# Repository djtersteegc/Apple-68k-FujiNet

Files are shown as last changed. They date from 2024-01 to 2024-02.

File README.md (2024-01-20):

Repo for early testing of FujiNet PCB's for 68k Apple Macs

# Rev0

Schematic - https://djtersteegc.github.io/Apple-68k-FujiNet/Apple-68k-FujiNet-Rev0-Schematic.pdf

Interactive BOM - https://djtersteegc.github.io/Apple-68k-FujiNet/ibom-Rev0.html

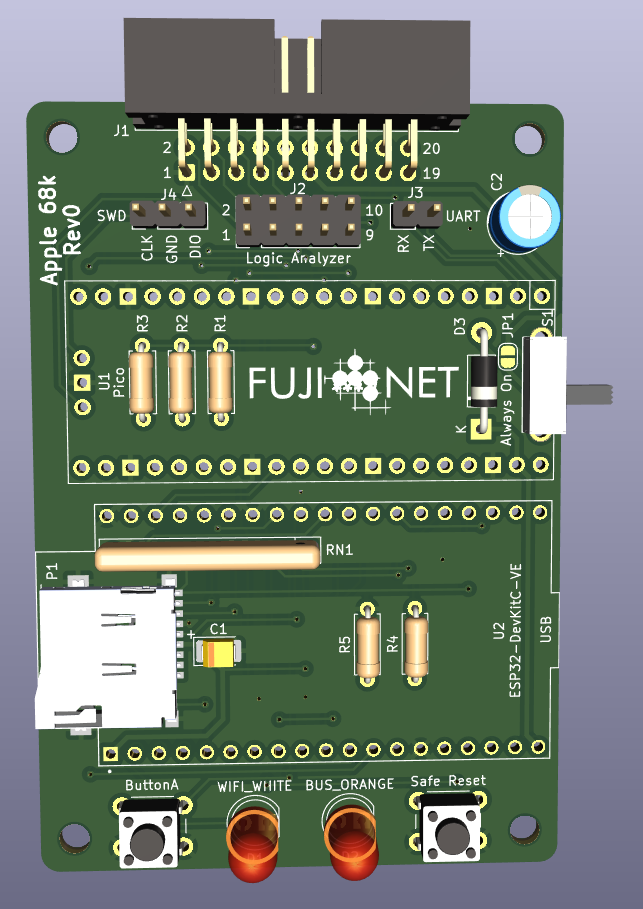
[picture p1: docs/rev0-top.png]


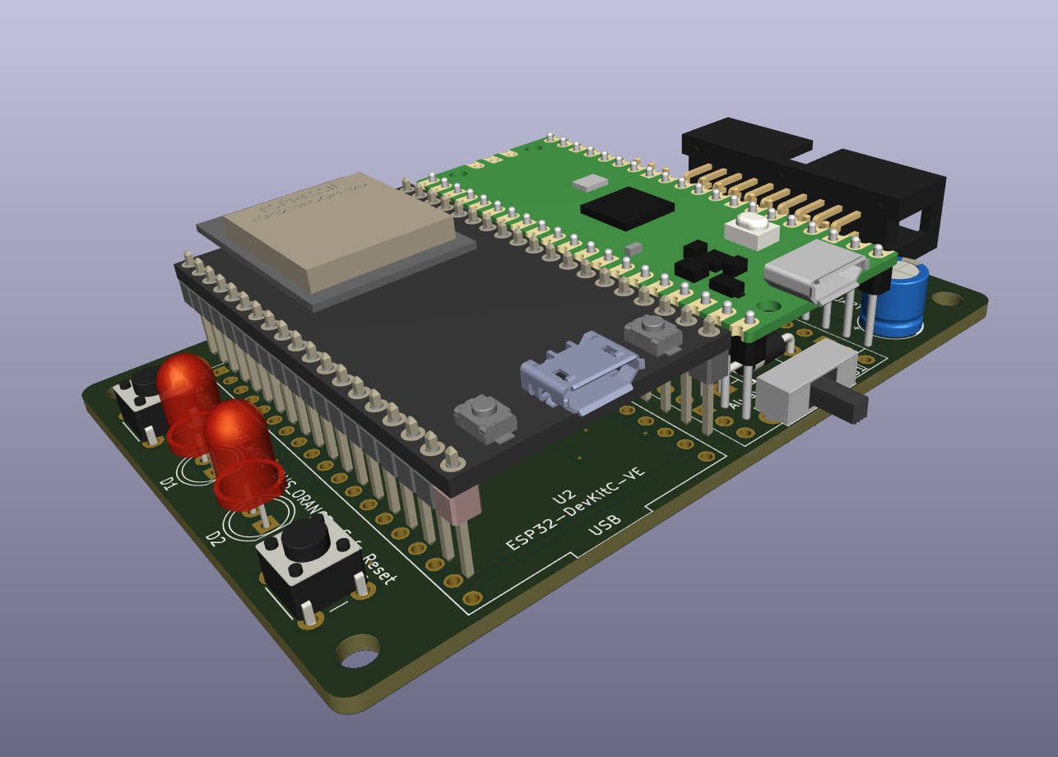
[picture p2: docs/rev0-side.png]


C1 and C2 can be considered optional, board should work without them.

You'll need 8.5mm high [2.54mm female header strips](https://www.aliexpress.us/item/2251832416528370.html) to mount the ESP32 and Pi Pico.  Buy the 1x40 versions and cut to length.

The switch controls power from the Mac DB19 port. Can be bridged via JP1 if you don't want to install and always be powered. The footprint also takes the common [**12D07VG4**](https://www.aliexpress.us/item/2255801015765871.html) you find on AliExpress.

MicroSD socket footprint is the common [Chinese push-push version](https://www.aliexpress.us/item/2251832613969983.html) used on all the FujiNet's to date.

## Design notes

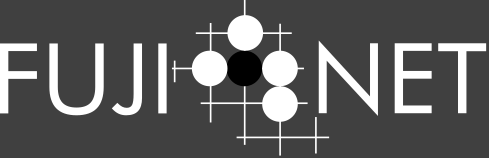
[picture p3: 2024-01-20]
docs/FujiNet-Header.png

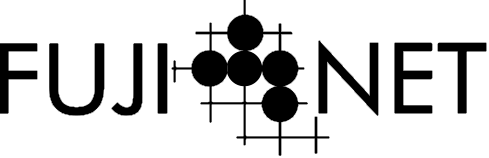
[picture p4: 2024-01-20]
docs/FujiNet-Header-Black.png

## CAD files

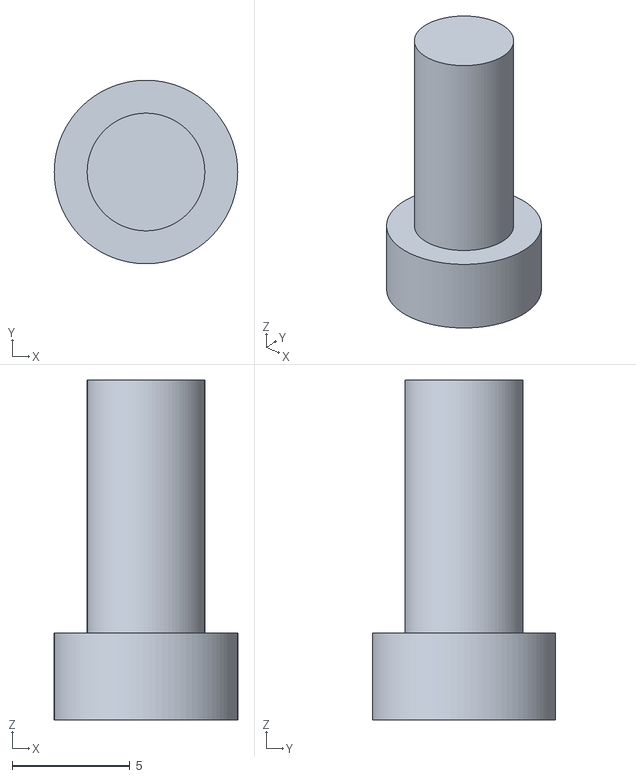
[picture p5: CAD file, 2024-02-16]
Apple-68k-FujiNet-Rev0/3D/STL/Apple-68k-FujiNet-Rev0-Button-4.3mm.stl
7.80 x 7.80 x 14.4

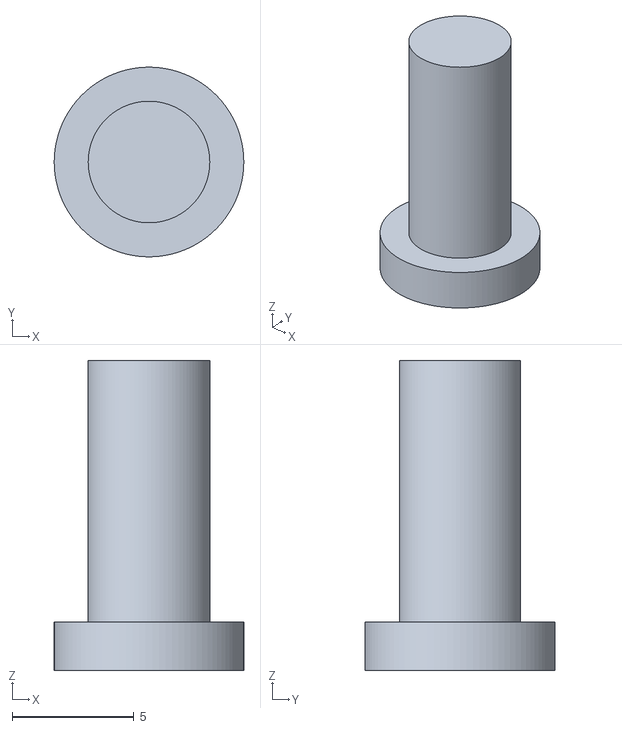
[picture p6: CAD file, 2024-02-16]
Apple-68k-FujiNet-Rev0/3D/STL/Apple-68k-FujiNet-Rev0-Button-6mm.stl
7.80 x 7.80 x 12.7

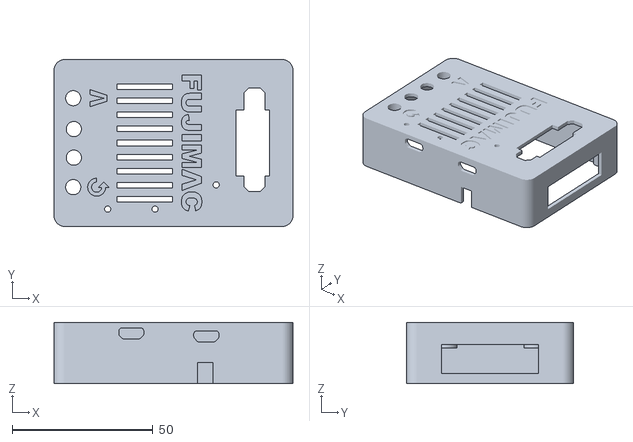
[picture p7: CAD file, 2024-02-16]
Apple-68k-FujiNet-Rev0/3D/STL/Apple-68k-FujiNet-Rev0-Body-Debug.stl
85.0 x 59.4 x 21.8

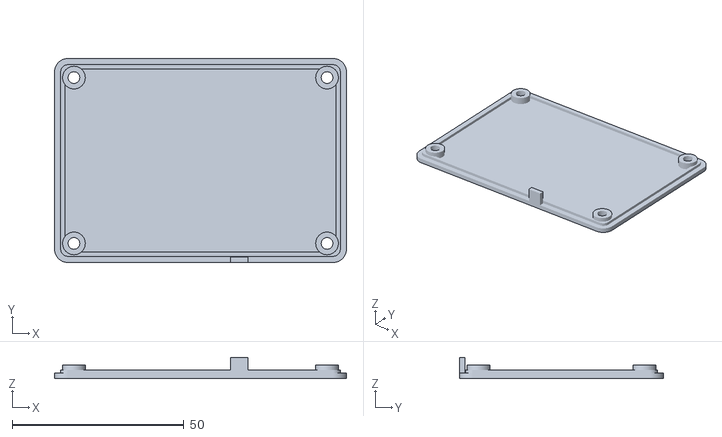
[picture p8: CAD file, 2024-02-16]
Apple-68k-FujiNet-Rev0/3D/STL/Apple-68k-FujiNet-Rev0-Lid.stl
85.0 x 59.4 x 6.25

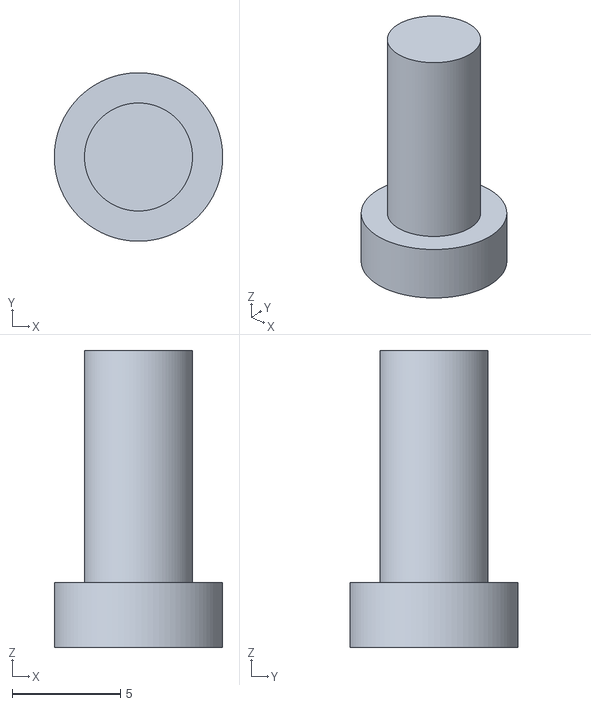
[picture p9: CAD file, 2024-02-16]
Apple-68k-FujiNet-Rev0/3D/STL/Apple-68k-FujiNet-Rev0-Button-5mm.stl
7.80 x 7.80 x 13.7

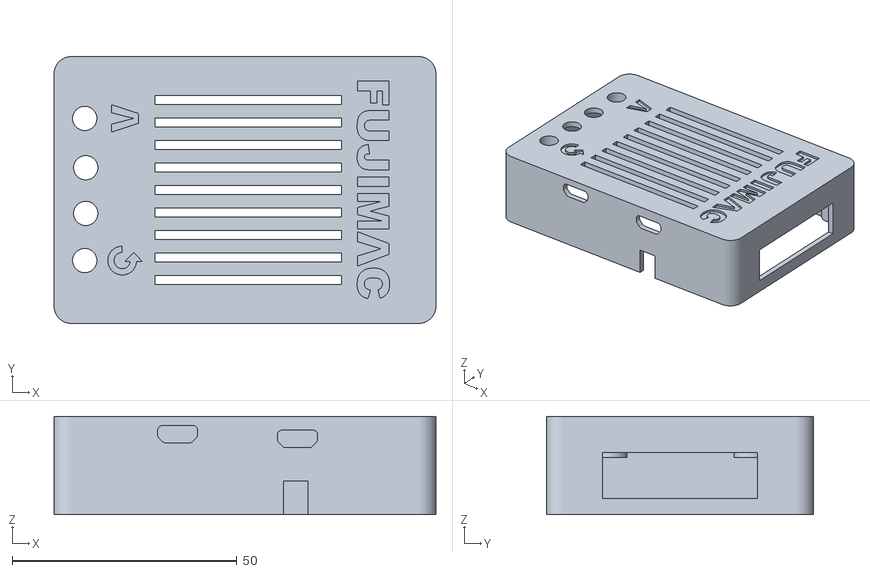
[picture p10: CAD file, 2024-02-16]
Apple-68k-FujiNet-Rev0/3D/STL/Apple-68k-FujiNet-Rev0-Body.stl
85.0 x 59.4 x 21.8

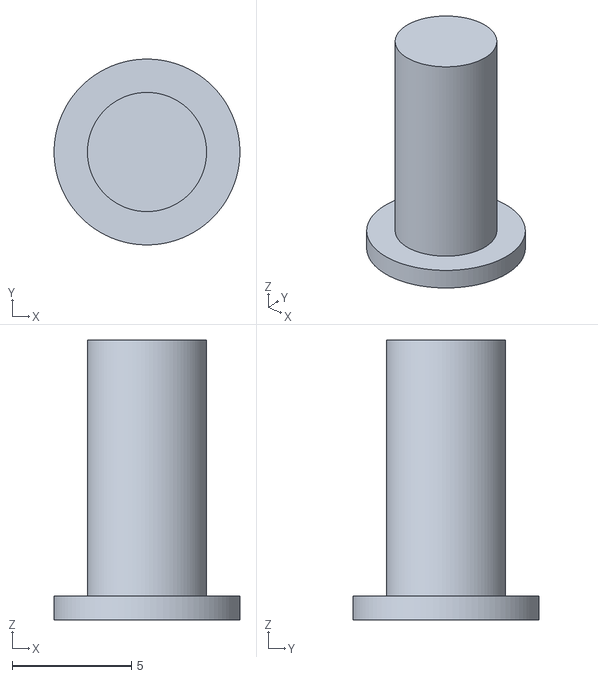
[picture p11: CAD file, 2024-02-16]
Apple-68k-FujiNet-Rev0/3D/STL/Apple-68k-FujiNet-Rev0-Button-7mm.stl
7.80 x 7.80 x 11.7

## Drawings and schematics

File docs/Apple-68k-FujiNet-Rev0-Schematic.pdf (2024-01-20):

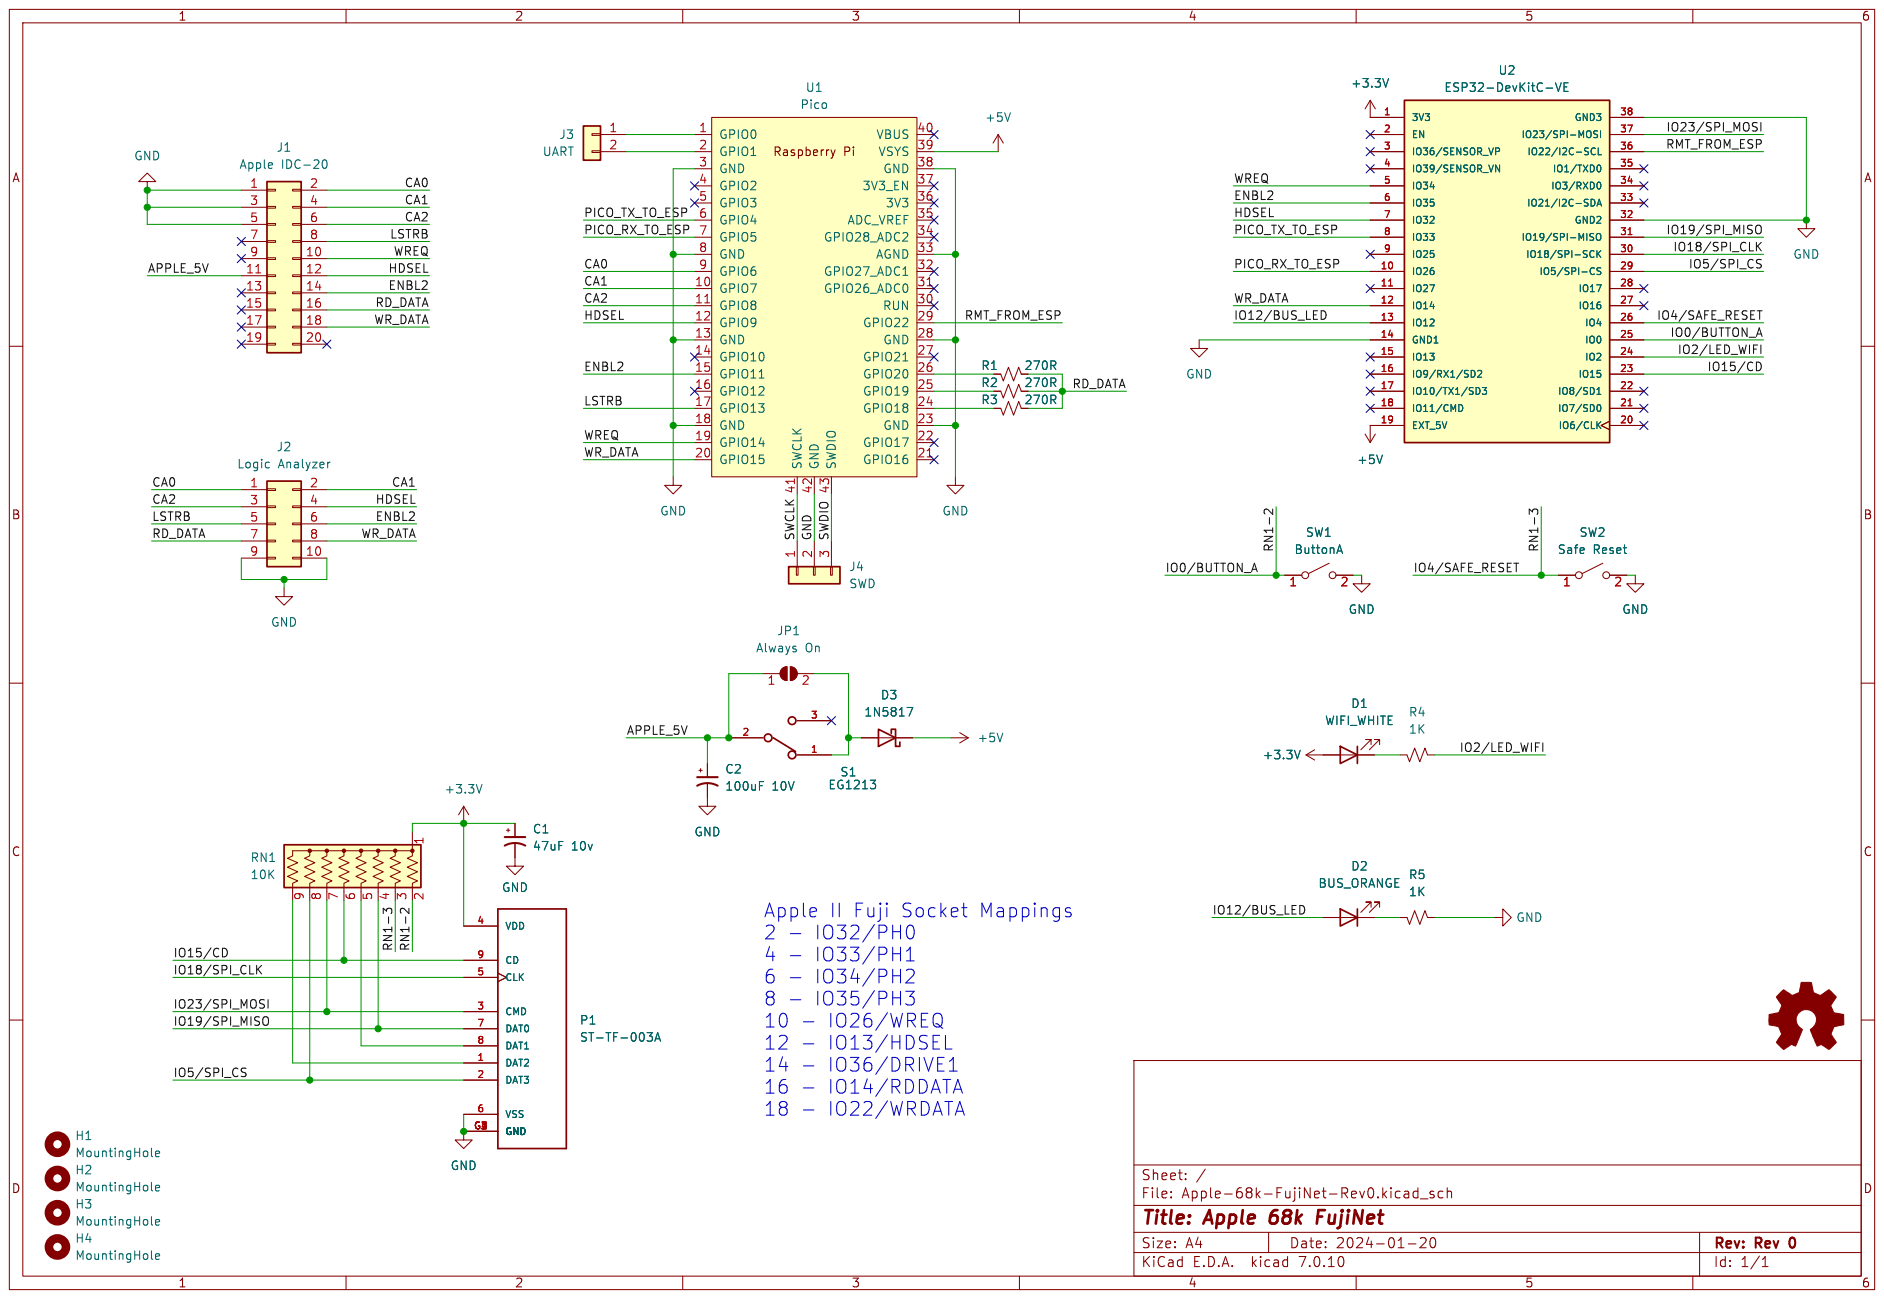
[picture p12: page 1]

Id: 1/1 Title: Apple 68k FujiNet File: Apple-68k-FujiNet-Rev0.kicad_sch Sheet: /

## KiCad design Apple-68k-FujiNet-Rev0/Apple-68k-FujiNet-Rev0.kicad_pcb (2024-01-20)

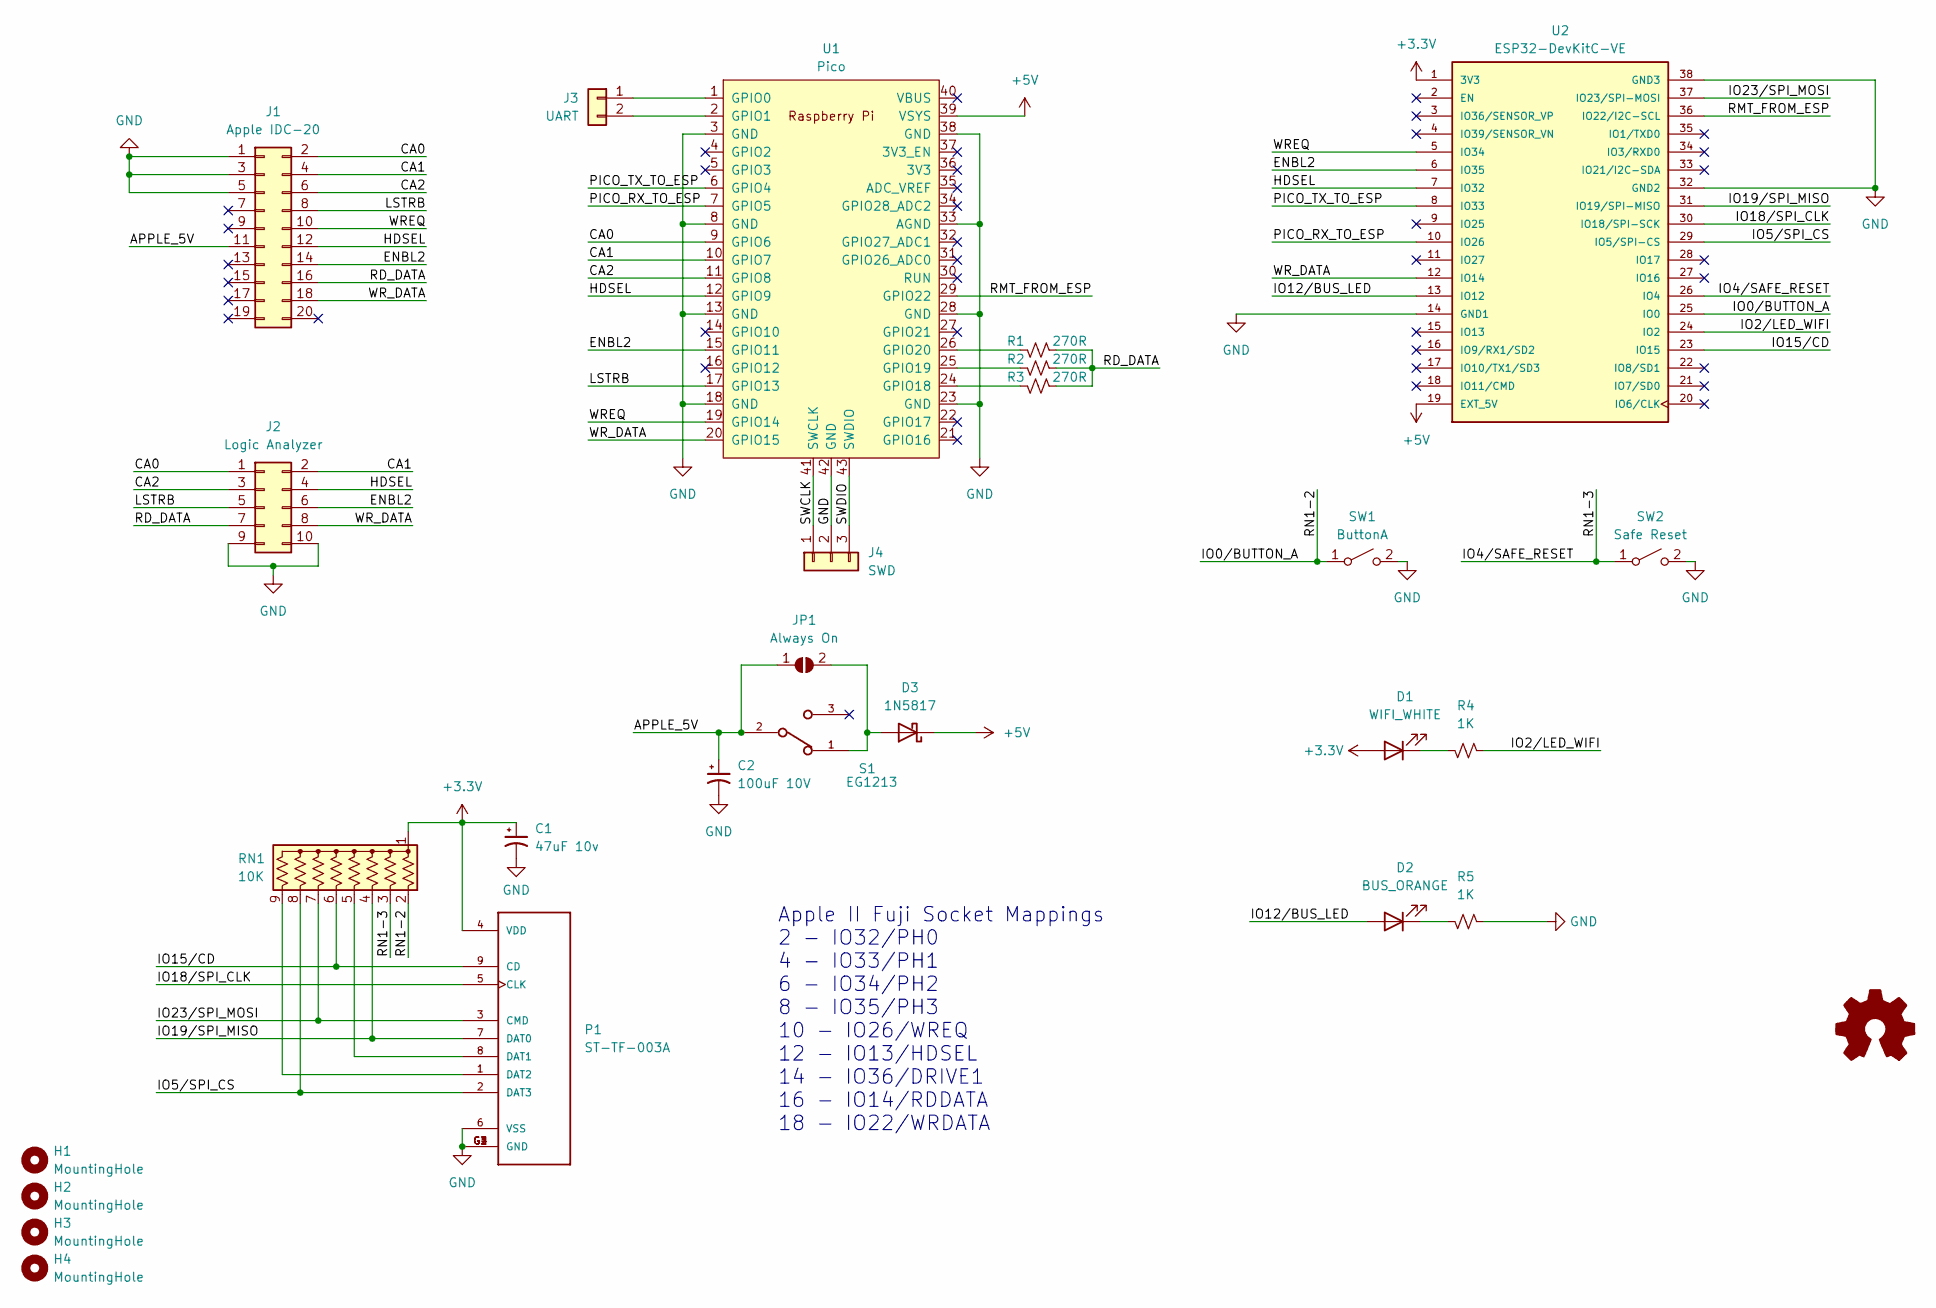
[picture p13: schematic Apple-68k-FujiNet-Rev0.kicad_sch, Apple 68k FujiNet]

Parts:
C1: 47uF 10v; CP_EIA-3528-15_AVX-H_Pad1.50x2.35mm_HandSolder
C2: 100uF 10V; CP_Radial_D6.3mm_P2.50mm
D1: WIFI_WHITE; LED_D5.0mm
D2: BUS_ORANGE; LED_D5.0mm
D3: 1N5817; D_DO-41_SOD81_P10.16mm_Horizontal
H1, H2, H3, H4: MountingHole; MountingHole_3.2mm_M3
J1: Apple IDC-20; IDC-Header_2x10_P2.54mm_Horizontal
J2: Logic Analyzer; PinHeader_2x05_P2.54mm_Vertical
J3: UART; PinHeader_1x02_P2.54mm_Vertical
J4: SWD; PinHeader_1x03_P2.54mm_Vertical
JP1: Always On; SolderJumper-2_P1.3mm_Open_RoundedPad1.0x1.5mm
P1: ST-TF-003A; SUNTECH_ST-TF-003A
R1, R2, R3: 270R; R_Axial_DIN0207_L6.3mm_D2.5mm_P7.62mm_Horizontal
R4, R5: 1K; R_Axial_DIN0207_L6.3mm_D2.5mm_P7.62mm_Horizontal
RN1: 10K; R_Array_SIP9
S1: EG1213; SW_EG1213
SW1: ButtonA; SW_PUSH_6mm_H5mm
SW2: Safe Reset; SW_PUSH_6mm_H5mm
U1: Pico; RPi_Pico_THT
U2: ESP32-DevKitC-VE; MODULE_ESP32-DEVKITC-32U; PARTREV N/A

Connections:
+3.3V: C1.1, D1.2 (A), P1.4 (VDD), RN1.1 (common), U2.1 (3V3)
+5V: D3.1 (K), U1.39 (VSYS), U2.19 (EXT_5V)
/APPLE_5V: C2.1, J1.11, JP1.1 (A), S1.2
/CA0: J1.2, J2.1, U1.9 (GPIO6)
/CA1: J1.4, J2.2, U1.10 (GPIO7)
/CA2: J1.6, J2.3, U1.11 (GPIO8)
/ENBL2: J1.14, J2.6, U1.15 (GPIO11), U2.6 (IO35)
/HDSEL: J1.12, J2.4, U1.12 (GPIO9), U2.7 (IO32)
/IO0/BUTTON_A: RN1.2 (R1), SW1.1 (A), U2.25 (IO0)
/IO2/LED_WIFI: R4.2, U2.24 (IO2)
/IO4/SAFE_RESET: RN1.3 (R2), SW2.1 (A), U2.26 (IO4)
/IO5/SPI_CS: P1.2 (DAT3), RN1.8 (R7), U2.29 (IO5/SPI-CS)
/IO12/BUS_LED: D2.2 (A), U2.13 (IO12)
/IO15/CD: P1.9 (CD), RN1.6 (R5), U2.23 (IO15)
/IO18/SPI_CLK: P1.5 (CLK), U2.30 (IO18/SPI-SCK)
/IO19/SPI_MISO: P1.7 (DAT0), RN1.4 (R3), U2.31 (IO19/SPI-MISO)
/IO23/SPI_MOSI: P1.3 (CMD), RN1.7 (R6), U2.37 (IO23/SPI-MOSI)
/LSTRB: J1.8, J2.5, U1.17 (GPIO13)
/PICO_RX_TO_ESP: U1.7 (GPIO5), U2.10 (IO26)
/PICO_TX_TO_ESP: U1.6 (GPIO4), U2.8 (IO33)
/RD_DATA: J1.16, J2.7, R1.2, R2.2, R3.2
/RMT_FROM_ESP: U1.29 (GPIO22), U2.36 (IO22/I2C-SCL)
/SWCLK: J4.1, U1.41 (SWCLK)
/SWDIO: J4.3, U1.43 (SWDIO)
/WREQ: J1.10, U1.19 (GPIO14), U2.5 (IO34)
/WR_DATA: J1.18, J2.8, U1.20 (GPIO15), U2.12 (IO14)
GND: C1.2, C2.2, J1.1, J1.3, J1.5, J2.9, J2.10, J4.2, P1.6 (VSS), P1.G1 (GND), P1.G2 (GND), P1.G3 (GND), P1.G4 (GND), R5.2, SW1.2 (B), SW2.2 (B), U1.3 (GND), U1.8 (GND), U1.13 (GND), U1.18 (GND), U1.23 (GND), U1.28 (GND), U1.33 (AGND), U1.38 (GND), U1.42 (GND), U2.14 (GND1), U2.32 (GND2), U2.38 (GND3)
unnamed: D1.1 (K), R4.1
unnamed: D2.1 (K), R5.1
unnamed: D3.2 (A), JP1.2 (B), S1.1
unnamed: J3.1, U1.1 (GPIO0)
unnamed: J3.2, U1.2 (GPIO1)
unnamed: P1.8 (DAT1), RN1.5 (R4)
unnamed: P1.1 (DAT2), RN1.9 (R8)
unnamed: R3.1, U1.24 (GPIO18)
unnamed: R2.1, U1.25 (GPIO19)
unnamed: R1.1, U1.26 (GPIO20)

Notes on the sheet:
Apple II Fuji Socket Mappings 2 - IO32/PH0 4 - IO33/PH1 6 - IO34/PH2 8 - IO35/PH3 10 - IO26/WREQ 12 - IO13/HDSEL 14 - IO36/DRIVE1 16 - IO14/RDDATA 18 - IO22/WRDATA

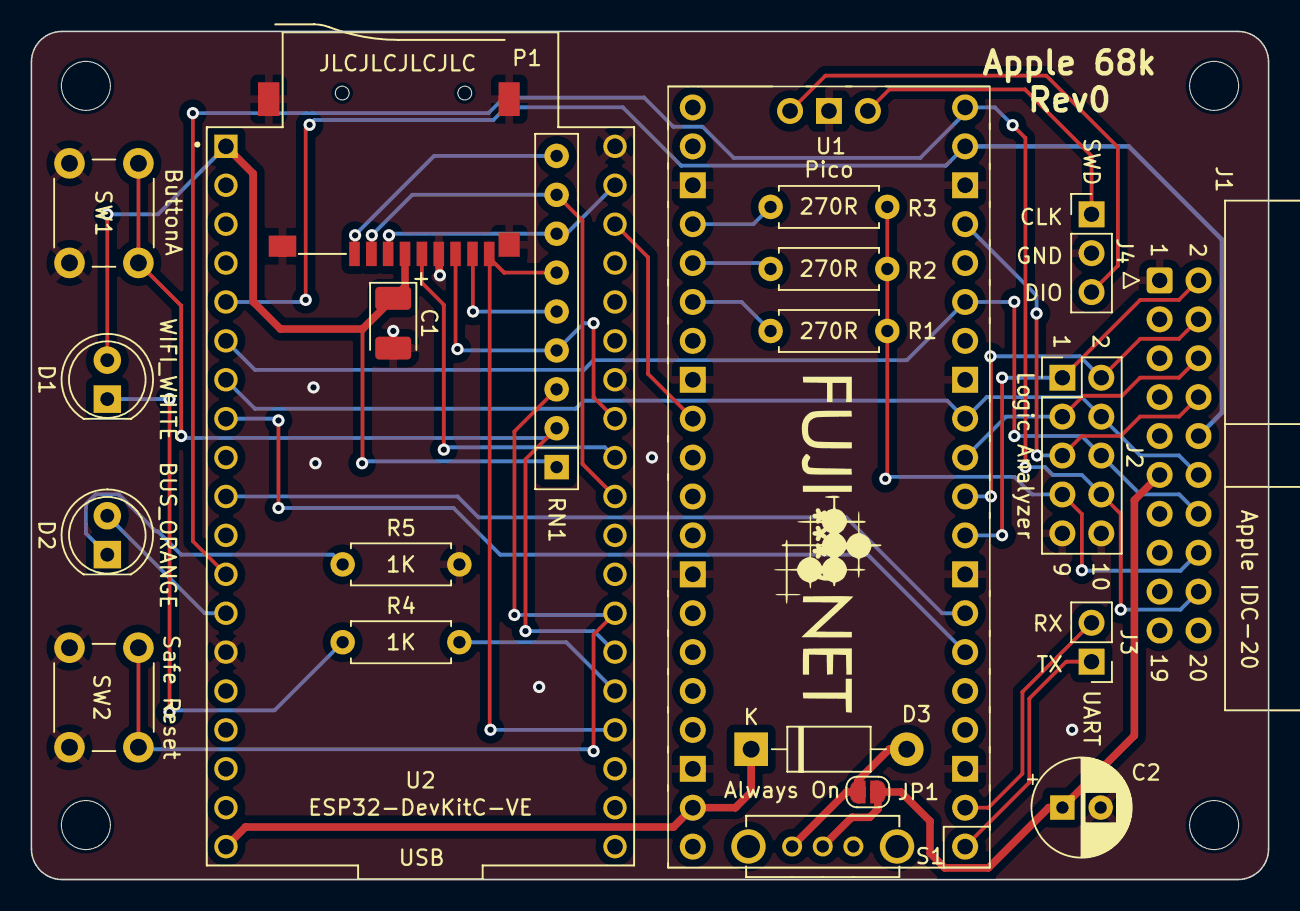
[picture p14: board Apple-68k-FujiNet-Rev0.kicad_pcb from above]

Board: 2 copper layers, 80.8 x 55.4 mm, 26 parts (0 on the bottom side), 37 nets.

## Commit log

2024-01-20 Remove ground on Pin 7 for Rev0 boards since Jeff may also use these for Apple II development
    [Apple-68k-FujiNet-Rev0-B_Cu.gbr, Apple-68k-FujiNet-Rev0-B_Mask.gbr, Apple-68k-FujiNet-Rev0-B_Paste.gbr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]
2024-01-20 Update Schematic to remove GND on pin 7
2024-01-20 Add 3D board renders for assembly guidance
    [Apple-68k-FujiNet-Rev0.kicad_pcb]
2024-02-09 Initial stab at a case for Rev0
    [Apple-68k-FujiNet-Rev0-Body.stl, Apple-68k-FujiNet-Rev0-Button.stl, Apple-68k-FujiNet-Rev0-Lid.stl]
2024-02-16 Tweak clearances, add button options, add new body with cutout for headers and modules buttons
    [Apple-68k-FujiNet-Rev0-Body-Debug.stl, Apple-68k-FujiNet-Rev0-Body.stl, Apple-68k-FujiNet-Rev0-Button-4.3mm.stl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]
